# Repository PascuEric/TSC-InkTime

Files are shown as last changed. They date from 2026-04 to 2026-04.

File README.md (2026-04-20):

# InkTime — Smartwatch

InkTime is an open-source, minimalist smartwatch built around an always-readable 1.54" e-paper display and optimized for month-class battery life (≥30 days on a 250 mAh LiPo). It features BLE 5.0 notifications, embedded step counting, haptic alerts, and USB-C charging.

---

## Block Diagram

```
                          ┌──────────────────────────────────────────┐
         USB-C            │           nRF52840 (U1)                  │
        ──────►──┐        │                                          │
                 │  VBUS  │  ┌─────────────────────────────────┐     │
                 ▼        │  │         I2C Bus                 │     │
          ┌──────────┐    │  │  SDA P0.06 / SCL P0.07          │     │
          │ BQ25180  │◄───┼──┤  Pull-up 3K3 to 3V3             │     │
          │  (IC1)   │    │  │                                 │     │
          │ Charger  │    │  │  BQ25180 (0x6A)  RT6160 (0x75)  │     │
          └────┬─────┘    │  │  MAX17048 (0x36) BMA421 (0x18)  │     │
               │ SYS      │  │  DRV2605L (0x5A)                │     │
          ┌────▼─────┐    │  └─────────────────────────────────┘     │
          │ RT6160   │◄───┤                                          │
          │  (IC9)   │    │  ┌─────────────────────────────────┐     │
          │Buck-Boost│    │  │        SPI Bus                  │     │
          └────┬─────┘    │  │  SCK P0.02 / MOSI P0.03         │     │
               │ 3V3      │  │  CS P0.05 / DC P0.15            │     │
               ▼          │  │  RST P0.16 / BUSY P0.17         │     │
    ┌──────────────────┐  │  │  PFET gate P1.01                │     │
    │   3V3 Power Rail │  │  │                                 │     │
    └─┬───┬───┬───┬────┘  │  │  E-Paper 1.54" 200x200 (J1)     │     │
      │   │   │   │       │  │  via SI1308EDL MOSFET (Q3)      │     │
      │   │   │   │       │  └─────────────────────────────────┘     │
      │   │   │   │       │                                          │
      │   │   │   │       │  GPIO                                    │
      │   │   │   └───────┼──► SW_UP P0.13 / SW_DN P0.14             │
      │   │   │           │    SW_ENT P1.00                          │
      │   │   │           │  INT: BMA421 INT1→P0.08 INT2→P1.08       │
      │   │   │           │       MAX17048 ALRT→P0.10                │
      │   │   │           │       BQ25180 /INT→P0.11                 │
      │   │   │           │       HAPTIC_EN→P0.12                    │
      │   │   │           │                                          │
      │   │   │           │  RF: ANT→L1(3.9nH)→L3(15nH)→ANT1         │
      │   │   │           │  USB: D+/D-→USBLC6(D3)→USB-C (J4)        │
      │   │   │           │  SWD: SWDIO/SWDCLK/RESET→TC2030 (J2)     │
      │   │   │           └──────────────────────────────────────────┘
      │   │   │
      │   │  ┌▼────────────┐    ┌──────────────┐
      │   │  │  DRV2605L   ├───►│  ERM Motor   │
      │   │  │  (IC2) I2C  │    │  (Haptic)    │
      │   │  └─────────────┘    └──────────────┘
      │   │
      │  ┌▼────────────┐
      │  │   BMA421    │
      │  │   (IC3) I2C │  INT1→P0.08 / INT2→P1.08
      │  └─────────────┘
      │
     ┌▼────────────┐
     │  MAX17048   │
     │  (U3) I2C   │  ALRT→P0.10
     └─────────────┘

  ┌──────────┐
  │  LiPo    │──VBAT──► BQ25180 (BAT) ──► MAX17048 (BAT/VDD)
  │ 250 mAh  │
  └──────────┘
```

---

## Bill of Materials (BOM)

| Qty | Ref | Component | Package | Description | JLCPCB | Datasheet |
|-----|-----|---|---|---|---|---|
| 1 | U1 | nRF52840-QIAA-R | aQFN73 | MCU BLE 5.0 + USB 2.0 | — | [Link](https://infocenter.nordicsemi.com/pdf/nRF52840_PS_v1.7.pdf) |
| 1 | IC1 | BQ25180YBGR | DSBGA-8 | LiPo charger / power path | [C3682423](https://jlcpcb.com/partdetail/TexasInstruments-BQ25180YBGR/C3682423) | [Link](https://www.ti.com/lit/ds/symlink/bq25180.pdf) |
| 1 | IC9 | RT6160AWSC | WLCSP-15 | Buck-boost 3.3V regulator | [C7065276](https://jlcpcb.com/partdetail/Richtek-RT6160AWSC/C7065276) | [Link](https://www.richtek.com/assets/product_file/RT6160A/DS6160A-00.pdf) |
| 1 | U3 | MAX17048G+T10 | DFN-8 | Fuel gauge I2C | — | [Link](https://datasheets.maximintegrated.com/en/ds/MAX17048-MAX17049.pdf) |
| 1 | IC3 | BMA421 | LGA-12 | Accelerometer + step counter | — | [Link](https://www.bosch-sensortec.com/media/boschsensortec/downloads/datasheets/bst-bma421-ds000.pdf) |
| 1 | IC2 | DRV2605YZFR | DSBGA-9 | Haptic driver ERM/LRA | — | [Link](https://www.ti.com/lit/ds/symlink/drv2605l.pdf) |
| 1 | Q3 | SI1308EDL-T1-GE3 | SC-70 | N-ch MOSFET EPD power gate | — | [Link](https://www.vishay.com/docs/63587/si1308edl.pdf) |
| 1 | DMG2305UX-7 | DMG2305UX-7 | SOT-23 | P-ch MOSFET EPD drive | — | — |
| 1 | ANT1 | 2450AT18B100E | SMD 3216 | 2.45 GHz chip antenna | — | [Link](https://www.johansontechnology.com/datasheets/2450AT18B100E/2450AT18B100E.pdf) |
| 1 | J4 | KH-TYPE-C-16P | THT | USB-C 16-pin connector | — | — |
| 1 | D3 | USBLC6-2SC6Y | SOT-23-6 | USB ESD protection | — | [Link](https://www.st.com/resource/en/datasheet/usblc6-2.pdf) |
| 3 | D2,D4,D5 | MBR0530 | SOD-123 | Schottky diode 30V 500mA | — | — |
| 1 | J2 | TC2030-IDC | PCB footprint | Tag-Connect SWD debug | — | [Link](https://www.tag-connect.com/wp-content/uploads/bsk-pdf-manager/TC2030-IDC_1.pdf) |
| 1 | J1 | 503480-2400 | FPC 24-pin | E-paper FPC connector 0.5mm | — | [Mouser](https://www.mouser.co.uk/ProductDetail/Molex/503480-2400) |
| 3 | SW_UP,SW_DN,SW_ENT | EVP-AKE31A | SMD | Tactile button Panasonic | — | — |
| 1 | X1 | 32 MHz crystal | 2016 SMD | HFXO nRF52840 | — | — |
| 1 | X2 | 32.768 kHz crystal | 3215 SMD | LFXO RTC nRF52840 | — | — |
| 1 | L7 | FTC252012SR47MBCA | 2520 | 0.47 µH RT6160 switching | [C5832368](https://jlcpcb.com/partdetail/6763488-FTC252012SR47MBCA/C5832368) | — |
| 1 | L2 | 10 µH | 0402 | RT6160 power stage | — | — |
| 1 | L3 | 15 nH | 0402 | RF matching network | — | — |
| 1 | L1 | 3.9 nH | 0402 | RF matching network | — | — |
| 1 | L5 | 68 µH | 0402 | EPD boost converter | — | — |
| 5 | C5,C7,C8,C12,C19 | 100 nF | 0201 | Decoupling nRF52840 | — | — |
| 4 | C1,C2,C17,C18 | 12 pF | 0201 | Crystal load caps | — | — |
| 6 | C29–C32,C37,C38 | 1 µF | 0201 | Bulk decoupling | — | — |
| 3 | C23,C27,C42 | 0.1 µF | 0201 | Decoupling | — | — |
| 2 | C25,C33 | 22 µF | 0402 | RT6160 output caps | — | — |
| 3 | C14,C20,C21 | 4.7 µF | 0402 | Bulk decoupling | — | — |
| 1 | C43 | 4.7 µF | 0402 | DECUSB nRF52840 | — | — |
| 1 | C24 | 10 µF | 0402 | RT6160 input cap | — | — |
| 9 | EPD_C1..C12 | 1 µF/50V | 0402 | EPD supply caps | — | — |
| 1 | C15 | 1.0 µF | 0201 | DEC4/6 nRF52840 | — | — |
| 1 | C11 | 100 pF | 0201 | RF matching | — | — |
| 2 | C3,C4 | 1 pF | 0201 | RF matching | — | — |
| 1 | C9 | 820 pF | 0201 | RF decoupling | — | — |
| 2 | R17,R18 | 3.3 kΩ | 0201 | I2C pull-ups SDA/SCL | — | — |
| 3 | R5,R7,R8 | 10 kΩ | 0201 | Button pull-ups | — | — |
| 2 | R1_USB,R2_USB | 5.1 kΩ | 0201 | USB CC1/CC2 resistors | — | — |
| 14 | TP_* | Test pad | TP20R | Test points | — | — |
| 1 | SJ1 | Solder jumper | SMD | Config jumper | — | — |

---

## Hardware Functionality Description

### Power Architecture

```
USB 5V → BQ25180 (IN) → BQ25180 (SYS) → RT6160 (VIN) → 3.3V rail
LiPo   → BQ25180 (BAT) and LiPo → MAX17048 (BAT/VDD)
```

**BQ25180 (IC1)** handles LiPo charging and power-path management. When USB is present, it powers the system from USB and charges the battery simultaneously without brownout on connect/disconnect. TS/MR strapped to GND (R9, 10kΩ) for Rev A. Decoupling: C37 (1µF on IN), C39 (10µF on SYS), C38 (1µF on BAT).

**RT6160 (IC9)** is a buck-boost maintaining stable 3.3V across the full LiPo discharge range (4.2V → 3.0V). VSEL tied low for 3.3V output. EN tied to VSYS (always on when SYS present). Switching inductor L7 (0.47µH) placed close to SW pins. Output caps C25 + C33 (22µF each).

**MAX17048 (U3)** reports battery state-of-charge over I2C (0x36) using the ModelGauge algorithm, requiring no sense resistor. ALRT output (active-low) on P0.10 wakes MCU when battery drops below threshold.

### MCU — nRF52840 (U1)

ARM Cortex-M4F, 64 MHz, BLE 5.0, USB 2.0 Full Speed. Normal-voltage mode (VDD = 3.3V). Internal DC/DC regulator (REG1) enabled in firmware to reduce active-mode current.

Decoupling placed directly at MCU pins: DEC1 → C7 (100nF), DEC3 → C8 (100nF), DEC4/DEC6 → C15 (1µF), DECUSB → C43 (4.7µF). DC/DC network: DCC → L2 (10µH) → L3 (15nH) → DEC4/6 node.

### I2C Bus

SDA P0.06 / SCL P0.07, pull-ups R17+R18 (3.3kΩ to 3V3), 100 kHz default.

| Device | Address | Function |
|---|---|---|
| BMA421 (IC3) | 0x18 | Accelerometer + step counter |
| MAX17048 (U3) | 0x36 | Fuel gauge |
| DRV2605L (IC2) | 0x5A | Haptic driver |
| BQ25180 (IC1) | 0x6A | Charger / power path |
| RT6160 (IC9) | 0x75 | Buck-boost regulator |

### E-Paper Display (J1)

1.54" 200×200 e-paper via Molex 503480-2400 24-pin FPC connector (0.5mm pitch). SPI communication. VEPD switched by SI1308EDL N-ch MOSFET (Q3, gate P1.01) for complete power gating between updates. EPD boost circuit: D2, D4, D5 (MBR0530) + L5 (68µH) + DMG2305UX-7 generates PREVGL/PREVGH panel voltages. Optional DNP series resistors on SPI lines prevent back-powering when VEPD off.

### Accelerometer — BMA421 (IC3)

Embedded step counter running autonomously. I2C 0x18 (CSB high, SDO low). INT1 → P0.08 for motion/step wake; INT2 → P1.08 for secondary events. Placed away from ERM motor to avoid false motion coupling.

### Haptics — DRV2605L (IC2)

Drives ERM motor via I2C (0x5A). EN pin P0.12 shuts down driver completely between events. Built-in waveform library selectable by effect ID over I2C.

### RF — ANT1

Matching network: ANT → L1 (3.9nH) → L3 (15nH) → C3/C4 (1pF to GND) → 2450AT18B100E chip antenna. Antenna at PCB edge with physical cutout and GND keepout underneath.

### USB-C (J4)

USB 2.0 FS. D+/D- differential pair with matched lengths. USBLC6-2SC6Y (D3) ESD protection at connector entry. R1_USB + R2_USB (5.1kΩ each) on CC1/CC2 for USB-C sink detection.

### Energy Budget

| Condition | Current | Fraction | Avg µA |
|---|---|---|---|
| Deep sleep | ~3 µA | 98.8% | ~3.0 |
| EPD partial refresh (2s/min) | ~8 mA | 0.13% | ~10.4 |
| BLE notification | ~15 mA | 0.05% | ~7.5 |
| Haptic event | ~50 mA | 0.02% | ~10.0 |
| **Total** | | | **~31 µA** |

250 mAh / 0.031 mA ≈ **~33 days** typical use.

---

## nRF52840 Pin Assignment

| Pin | Net | Dir | Connected to | Rationale |
|-----|-----|-----|---|---|
| P0.02 | SCK | OUT | EPD display | SPI — high-speed Port 0 peripheral |
| P0.03 | MOSI | OUT | EPD display | SPI data out |
| P0.05 | EPD_CS | OUT | EPD display | SPI chip select |
| P0.06 | SDA | I/O | All I2C ICs | Nordic reference I2C pin |
| P0.07 | SCL | OUT | All I2C ICs | Nordic reference I2C pin |
| P0.08 | IMU_INT1 | IN | BMA421 INT1 | GPIO sense, wake from deep sleep |
| P0.10 | ALERT | IN | MAX17048 ALRT | Low battery wake |
| P0.11 | PMIC_INT | IN | BQ25180 /INT | Charger event interrupt |
| P0.12 | HAPTIC_EN | OUT | DRV2605L EN | Haptic driver shutdown between events |
| P0.13 | SW_UP | IN | Button UP | GPIO sense + internal pull-up, wake capable |
| P0.14 | SW_DN | IN | Button DOWN | GPIO sense + internal pull-up, wake capable |
| P0.15 | EPD_DC | OUT | EPD display | Data/command select |
| P0.16 | EPD_RST | OUT | EPD display | Panel reset |
| P0.17 | EPD_BUSY | IN | EPD display | Busy status |
| P0.18/RESET | nRESET | IN | TC2030 pin 6 | Dedicated hardware reset |
| P0.00/XL1 | LFXO | — | X2 crystal | 32.768 kHz RTC |
| P0.01/XL2 | LFXO | — | X2 crystal | 32.768 kHz RTC |
| XC1/XC2 | HFXO | — | X1 crystal | 32 MHz RF/CPU |
| ANT | RF | — | L1→L3→ANT1 | Antenna matching network |
| VBUS | Detect | IN | USB-C VBUS | USB attach detection |
| D+/D- | USB | I/O | USBLC6→J4 | USB 2.0 FS differential pair |
| SWDIO | SWD | I/O | TC2030 pin 2 | Programming + debug |
| SWDCLK | SWD | IN | TC2030 pin 4 | Programming + debug |
| P1.00 | SW_ENT | IN | Button ENTER | GPIO sense + pull-up, wake capable |
| P1.01 | EPD_PWR | OUT | Q3 gate | EPD power gate control |
| P1.08 | IMU_INT2 | IN | BMA421 INT2 | Secondary accel events |
| DCC | DC/DC | — | L2 (10µH) | Internal regulator inductor |
| DEC1 | Decoupling | — | C7 (100nF) | Core decoupling |
| DEC3 | Decoupling | — | C8 (100nF) | Core decoupling |
| DEC4/DEC6 | Decoupling | — | C15 (1µF) | DC/DC output node |
| DECUSB | Decoupling | — | C43 (4.7µF) | USB PHY decoupling |

---

## PCB Design Notes

**Stackup:** 2-layer, FR4, 1.6mm. Top + Bottom copper (1oz), green soldermask, white silkscreen.

**Placement:** nRF52840 centered; RF matching + ANT1 at top-right board edge with physical PCB cutout and GND keepout under antenna; BQ25180 + RT6160 grouped away from antenna; BMA421 separated from ERM motor; all 100nF decoupling within 0.5mm of VDD pins; TC2030 at board edge.

**Trace widths:** Power (3V3, VBAT) = 0.3mm; signals (SPI, I2C, GPIO) ≥ 0.15mm; USB D+/D- = 0.15mm matched length. No 90° angles.

**GND:** Polygon on Top + Bottom layers, via stitching throughout, especially dense around RF section.

---

## Repository Structure

```
├── Hardware/
│   ├── schemTSC.sch
│   └── schemaPCB.brd
├── Manufacturing/
│   ├── gerbers.zip
│   ├── bom.csv
│   └── pick-n-place.csv
├── Mechanical/
│   ├── casedPCB.step
│   └── exploded_case.step
├── Images/
│   ├── exploded_render.png
│   ├── PCB_render.png
│   ├── PCB_top.png
│   └── PCB_bottom.png
├── LICENSE
└── README.md
```

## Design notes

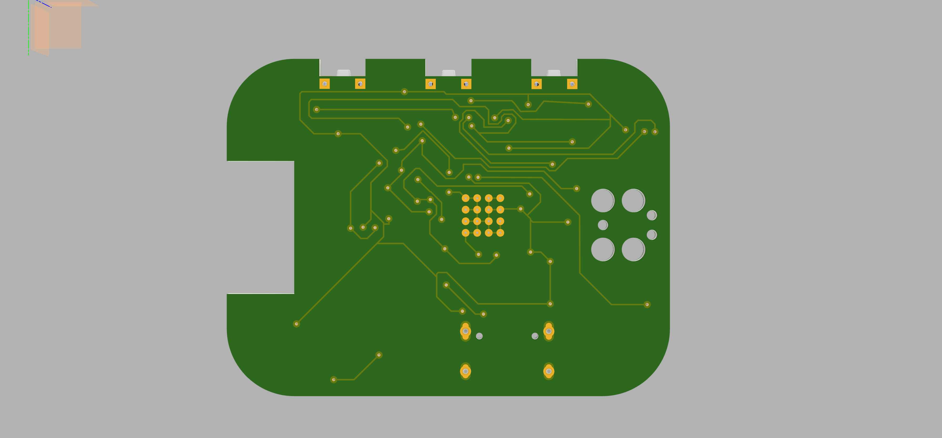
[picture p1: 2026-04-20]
images/PCB_bottom.png

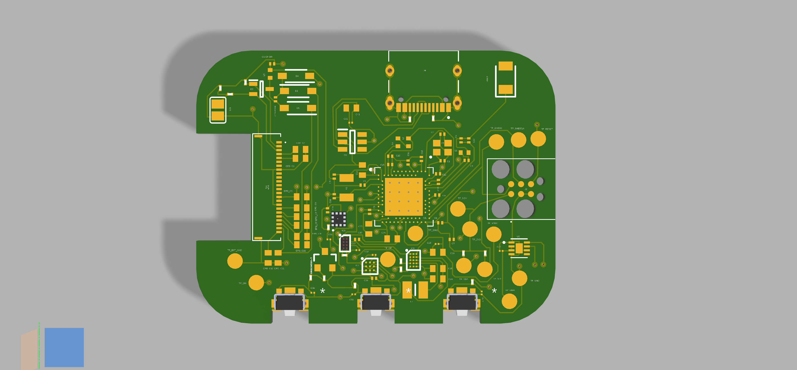
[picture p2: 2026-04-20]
images/PCB_top.png

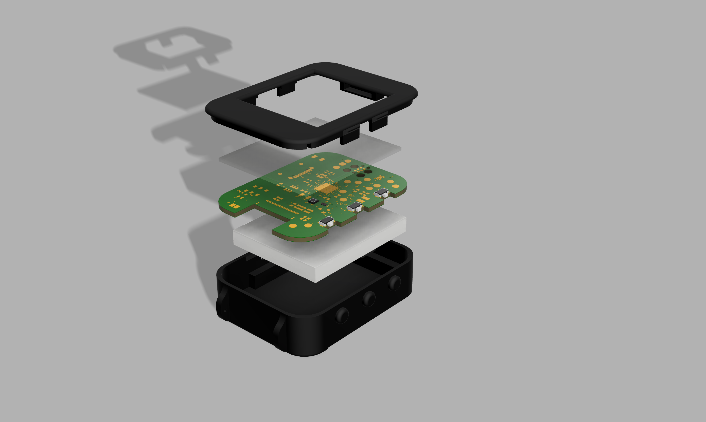
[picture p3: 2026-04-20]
images/exploded_render.png

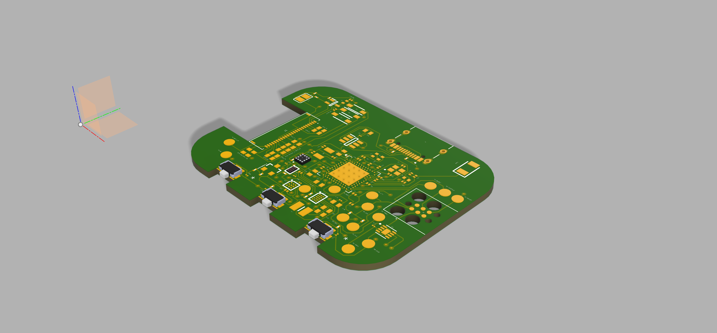
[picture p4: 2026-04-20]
images/PCB_render.png

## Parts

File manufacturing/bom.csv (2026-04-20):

Qty | Value | Device | Package | Parts | Description | ARROW_PART_NUMBER | ARROW_PRICE-STOCK | AVAILABILITY | CHECK_PRICES | COPYRIGHT | DESCRIPTION | DIGI-KEY_PART_NUMBER_1 | DIGI-KEY_PART_NUMBER_2 | DIGI-KEY_PART_NUMBER_3 | HEIGHT | JLCPCB | MANUFACTURER_NAME | MANUFACTURER_PART_NUMBER | MF | MOUSER_PART_NUMBER | MOUSER_PRICE-STOCK | MP | PACKAGE | POPULARITY | PRICE | PROD_ID | PURCHASE-URL | SNAPEDA_LINK | SPICEMODEL | SPICEPREFIX | TP_SIGNAL_NAME | VALUE
1 |  | ESP32_C6_LIBRARY_7_JUMPER_SJ | ESP32_C6_LIBRARY_7_JUMPER_SJ | SJ1 | SMD solder JUMPER |  |  |  |  |  |  |  |  |  |  |  |  |  |  |  |  |  |  | 3
2 | 0 | CPF0201D7K68C1_CPF0201D7K68C1 | CPF0201D7K68C1_0201 | R2, R4 | 7.68k 0201 Thin Film Surface Mount Fixed Resistor +/-0.5% 0.031W CPF0201D7K68C1
1 | 0 | ERA-1AEB3401C_CPF0201D7K68C1 | ERA-1AEB3401C_0201 | R3 | 7.68k 0201 Thin Film Surface Mount Fixed Resistor +/-0.5% 0.031W CPF0201D7K68C1
3 | 0.1uF | GRM011R60J152KE01L_2_GRM011R60J152KE01L | GRM011R60J152KE01L_2_CAPC0201X13N | C23, C27, C42 | Check availability |  |  | In Stock | https://www.snapeda.com/parts/GRM011R60J152KE01L/Murata/view-part/?ref=eda |  | SMD Capacitor X5R(EIA) with Capacitance: 1500pF Tol. 10%. Rated Voltage: 6.3Vdc |  |  |  |  |  |  |  | Murata |  |  | GRM011R60J152KE01L | 0201 Murata |  | None |  |  | https://www.snapeda.com/parts/GRM011R60J152KE01L/Murata/view-part/?ref=snap
1 | 0.1uF | NORDIC_NRF_3_CAPACITOR_0201_L | NORDIC_NRF_3_RESC0201_L | C34 | Generic chip capacitor
1 | 0.1uF/50V | ESP32_C6_LIBRARY_1_ESP32_WROVER_EAGLE-LTSPICE_CC0402 | ESP32_C6_LIBRARY_1_ESP32_WROVER_EAGLE-LTSPICE_C0402 | EPD_C5 | CAPACITOR, European symbol |  |  |  |  |  |  |  |  |  |  |  |  |  |  |  |  |  |  |  |  |  |  |  | NONE | C
1 | 0.47 | ERA-1AEB3401C_CPF0201D7K68C1 | ERA-1AEB3401C_0201 | R1_EP_DR | 7.68k 0201 Thin Film Surface Mount Fixed Resistor +/-0.5% 0.031W CPF0201D7K68C1
1 | 1.0µF | NORDIC_NRF_3_CAPACITOR_0201_L | NORDIC_NRF_3_RESC0201_L | C15 | Generic chip capacitor
5 | 100nF | NORDIC_NRF_3_CAPACITOR_0201_L | NORDIC_NRF_3_RESC0201_L | C5, C7, C8, C12, C19 | Generic chip capacitor
1 | 100pF | NORDIC_NRF_3_CAPACITOR_0201_L | NORDIC_NRF_3_RESC0201_L | C11 | Generic chip capacitor
1 | 10K | CPF0201D7K68C1_CPF0201D7K68C1 | CPF0201D7K68C1_0201 | R_PWR_EPD | 7.68k 0201 Thin Film Surface Mount Fixed Resistor +/-0.5% 0.031W CPF0201D7K68C1
2 | 10K | ERA-1AEB3401C_CPF0201D7K68C1 | ERA-1AEB3401C_0201 | R2_EP_DR, R9 | 7.68k 0201 Thin Film Surface Mount Fixed Resistor +/-0.5% 0.031W CPF0201D7K68C1
3 | 10k | CPF0201D7K68C1_CPF0201D7K68C1 | CPF0201D7K68C1_0201 | R5, R7, R8 | 7.68k 0201 Thin Film Surface Mount Fixed Resistor +/-0.5% 0.031W CPF0201D7K68C1
1 | 10uF | ESP32_C6_LIBRARY_1_ESP32_WROVER_EAGLE-LTSPICE_CC0402 | ESP32_C6_LIBRARY_1_ESP32_WROVER_EAGLE-LTSPICE_C0402 | C24 | CAPACITOR, European symbol |  |  |  |  |  |  |  |  |  |  |  |  |  |  |  |  |  |  |  |  |  |  |  | NONE | C
2 | 10uF | NORDIC_NRF_3_CAPACITOR_0201_L | NORDIC_NRF_3_RESC0201_L | C1-EP-DR, C39 | Generic chip capacitor
1 | 10µH | NORDIC_NRF_2_INDUCTOR_0402_L | NORDIC_NRF_2_RESC0402_L | L2 | Generic chip inductor
4 | 12pF | NORDIC_NRF_3_CAPACITOR_0201_L | NORDIC_NRF_3_RESC0201_L | C1, C2, C17, C18 | Generic chip capacitor
1 | 15nH | NORDIC_NRF_2_INDUCTOR_0402_L | NORDIC_NRF_2_RESC0402_L | L3 | Generic chip inductor
2 | 1pF | NORDIC_NRF_3_CAPACITOR_0201_L | NORDIC_NRF_3_RESC0201_L | C3, C4 | Generic chip capacitor
6 | 1uF | GRM011R60J152KE01L_2_GRM011R60J152KE01L | GRM011R60J152KE01L_2_CAPC0201X13N | C29, C30, C31, C32, C37, C38 | Check availability |  |  | In Stock | https://www.snapeda.com/parts/GRM011R60J152KE01L/Murata/view-part/?ref=eda |  | SMD Capacitor X5R(EIA) with Capacitance: 1500pF Tol. 10%. Rated Voltage: 6.3Vdc |  |  |  |  |  |  |  | Murata |  |  | GRM011R60J152KE01L | 0201 Murata |  | None |  |  | https://www.snapeda.com/parts/GRM011R60J152KE01L/Murata/view-part/?ref=snap
9 | 1uF/50V | ESP32_C6_LIBRARY_1_ESP32_WROVER_EAGLE-LTSPICE_CC0402 | ESP32_C6_LIBRARY_1_ESP32_WROVER_EAGLE-LTSPICE_C0402 | EPD_C1, EPD_C2, EPD_C6, EPD_C7, EPD_C8, EPD_C9, EPD_C10, EPD_C11, EPD_C12 | CAPACITOR, European symbol |  |  |  |  |  |  |  |  |  |  |  |  |  |  |  |  |  |  |  |  |  |  |  | NONE | C
1 | 2.2 | ERA-1AEB3401C_CPF0201D7K68C1 | ERA-1AEB3401C_0201 | R_TYPE_SEL | 7.68k 0201 Thin Film Surface Mount Fixed Resistor +/-0.5% 0.031W CPF0201D7K68C1
3 | 2025-10-22_07-23-44_LIBRARY_EVP-AKE31ASW_EVP-AKE31A_PAN | 2025-10-22_07-23-44_LIBRARY_EVP-AKE31ASW_EVP-AKE31A_PAN | 2025-10-22_07-23-44_LIBRARY_SW_EVP-AKE31A_PAN | SW_DN, SW_ENT, SW_UP |  |  |  |  |  | Copyright (C) 2025 Ultra Librarian. All rights reserved. |  | P123437TR-ND | P123437CT-ND | P123437DKR-ND |  |  | Panasonic | EVP-AKE31A
1 | 20V/4.2A/52mΩ/1.4W | ESP32_C6_LIBRARY_4_ESP32_WROVER_SPARKFUN-DISCRETESEMI_MOSFET_PCH-DMG2305UX-7 | ESP32_C6_LIBRARY_4_ESP32_C6_LIBRARY_4_ESP32_C6_LIBRARY_4_ESP32_C6_LIBRARY_4_ESP32_WROVER_SPARKFUN-DISCRETESEMI_SOT23-3 | DMG2305UX-7 | P-channel MOSFETs |  |  |  |  |  |  |  |  |  |  |  |  |  |  |  |  |  |  |  |  | TRAN-14388 |  |  |  |  |  | 20V/4.2A/52mΩ/1.4W
2 | 22uF | ESP32_C6_LIBRARY_1_ESP32_WROVER_EAGLE-LTSPICE_CC0402 | ESP32_C6_LIBRARY_1_ESP32_WROVER_EAGLE-LTSPICE_C0402 | C25, C33 | CAPACITOR, European symbol |  |  |  |  |  |  |  |  |  |  |  |  |  |  |  |  |  |  |  |  |  |  |  | NONE | C
1 | 2450AT18B100E | 2450AT18B100E_2450AT18B100E | 2450AT18B100E_ANTC3216X140N | ANT1 | Antennas 2.45GHz ANTENNA | 2450AT18B100E | https://www.arrow.com/en/products/2450at18b100e/johanson-dielectrics?utm_currency=USD&region=nac |  |  |  | Antennas 2.45GHz ANTENNA |  |  |  | 1.4mm |  | JOHANSON TECHNOLOGY | 2450AT18B100E |  | 609-2450AT18B100E | https://www.mouser.co.uk/ProductDetail/Johanson-Technology/2450AT18B100E?qs=yCnrNFeXz%252Bh5MFsFIXGZGA%3D%3D
1 | 3.9nH | NORDIC_NRF_2_INDUCTOR_0402_L | NORDIC_NRF_2_RESC0402_L | L1 | Generic chip inductor
1 | 32.768kHz | NORDIC_NRF_1_XTAL_32KHZ | NORDIC_NRF_1_XTAL_3215_N | X2
1 | 32MHz | NORDIC_NRF_XTAL_32MHZ | NORDIC_NRF_BT-XTAL_2016_N | X1
2 | 3K3 | CPF0201D7K68C1_CPF0201D7K68C1 | CPF0201D7K68C1_0201 | R17, R18 | 7.68k 0201 Thin Film Surface Mount Fixed Resistor +/-0.5% 0.031W CPF0201D7K68C1
1 | 4.7uF | ESP32_C6_LIBRARY_1_ESP32_WROVER_EAGLE-LTSPICE_CC0402 | ESP32_C6_LIBRARY_1_ESP32_WROVER_EAGLE-LTSPICE_C0402 | C43 | CAPACITOR, European symbol |  |  |  |  |  |  |  |  |  |  |  |  |  |  |  |  |  |  |  |  |  |  |  | NONE | C
1 | 4.7uF/25V | NORDIC_NRF_3_CAPACITOR_0201_L | NORDIC_NRF_3_RESC0201_L | C2-EP-DR | Generic chip capacitor
3 | 4.7µF | ESP32_C6_LIBRARY_1_ESP32_WROVER_EAGLE-LTSPICE_CC0402 | ESP32_C6_LIBRARY_1_ESP32_WROVER_EAGLE-LTSPICE_C0402 | C14, C20, C21 | CAPACITOR, European symbol |  |  |  |  |  |  |  |  |  |  |  |  |  |  |  |  |  |  |  |  |  |  |  | NONE | C
1 | 4.7µF | NORDIC_NRF_3_CAPACITOR_0201_L | NORDIC_NRF_3_RESC0201_L | C6 | Generic chip capacitor
1 | 47nF | NORDIC_NRF_3_CAPACITOR_0201_L | NORDIC_NRF_3_RESC0201_L | C16 | Generic chip capacitor
1 | 503480-2400 | 503480-2400_503480-2400 | 503480-2400_5034802400 | J1 | FFC & FPC Connectors 0.5mm FPC RA SMT Dual Contact 24Ckt |  |  |  |  |  | FFC & FPC Connectors 0.5mm FPC RA SMT Dual Contact 24Ckt |  |  |  | 1.87mm |  | Molex | 503480-2400 |  | 538-503480-2400 | https://www.mouser.co.uk/ProductDetail/Molex/503480-2400?qs=OAhjpuo3Vu7efIoxFh9AOw%3D%3D
1 | 5K1 | CPF0201D7K68C1_CPF0201D7K68C1 | CPF0201D7K68C1_0201 | R1_USB | 7.68k 0201 Thin Film Surface Mount Fixed Resistor +/-0.5% 0.031W CPF0201D7K68C1
1 | 5K1 | ERA-1AEB3401C_CPF0201D7K68C1 | ERA-1AEB3401C_0201 | R2_USB | 7.68k 0201 Thin Film Surface Mount Fixed Resistor +/-0.5% 0.031W CPF0201D7K68C1
1 | 68uH | NORDIC_NRF_2_INDUCTOR_0402_L | NORDIC_NRF_2_RESC0402_L | L5 | Generic chip inductor
1 | 820pF | NORDIC_NRF_3_CAPACITOR_0201_L | NORDIC_NRF_3_RESC0201_L | C9 | Generic chip capacitor
1 | BMA421 | BMA423_BMA423 | BMA423_BMA423 | IC3 | Accelerometers Triaxial low-g 12bit Acceleration Sensor | BMA423 | https://www.arrow.com/en/products/bma423/bosch |  |  |  | Accelerometers Triaxial low-g 12bit Acceleration Sensor |  |  |  | 1mm |  | BOSCH | BMA423 |  | 262-BMA423 | https://www.mouser.co.uk/ProductDetail/Bosch-Sensortec/BMA423?qs=HXFqYaX1Q2xC%252BSgeGoX3mg%3D%3D
1 | BQ25180YBGR | BQ25180YBGR_BQ25180YBGR | BQ25180YBGR_BGA8C40P2X4_100X155X50 | IC1 | Charger IC Lithium Ion/Polymer, Lithium Iron Phosphate 8-DSBGA (1.6x1.1) | BQ25180YBGR | https://www.arrow.com/en/products/bq25180ybgr/texas-instruments?utm_currency=USD&region=nac |  |  |  | Charger IC Lithium Ion/Polymer | Lithium Iron Phosphate 8-DSBGA (1.6x1.1) |  |  |  | 0.5mm |  | Texas Instruments | BQ25180YBGR |  | 595-BQ25180YBGR | https://www.mouser.co.uk/ProductDetail/Texas-Instruments/BQ25180YBGR?qs=doiCPypUmgEWjAK%252BJAX6Tw%3D%3D
1 | DRV2605YZFR | DRV2605YZFR_DRV2605YZFR | DRV2605YZFR_BGA9C50P3X3_144X144X62 | IC2 | Haptic Driver for ERM/LRA with Built-In Library and Smart Loop Architecture | DRV2605YZFR | https://www.arrow.com/en/products/drv2605yzfr/texas-instruments?region=nac |  |  |  | Haptic Driver for ERM/LRA with Built-In Library and Smart Loop Architecture |  |  |  | 0.625mm |  | Texas Instruments | DRV2605YZFR
3 | ESP32_C6_LIBRARY_5_MBR0530 | ESP32_C6_LIBRARY_5_MBR0530 | ESP32_C6_LIBRARY_5_SOD3716X135N | D2, D4, D5 | ON SEMICONDUCTOR - MBR0530 - DIODE, SCHOTTKY, 0.5A, 30V, SOD-123 |  |  | In Stock | https://www.snapeda.com/parts/MBR0530/Onsemi/view-part/?ref=eda |  | Diode Schottky 30 V 500mA Surface Mount SOD-123 |  |  |  |  |  |  |  | ON Semiconductor |  |  | MBR0530 | SOD-123-2 ON Semiconductor |  | None |  | https://www.snapeda.com/api/url_track_click_mouser/?unipart_id=179458&manufacturer=ON Semiconductor&part_name=MBR0530&search_term=None | https://www.snapeda.com/parts/MBR0530/Onsemi/view-part/?ref=snap
1 | FTC252012SR47MBCA | MLP2016SR47MT0S1_FTC252012SR47MBCA | MLP2016SR47MT0S1_INDC2016X100N | L7 | SMD / SMT Inductors (Coils), L=0.47?H, L x W x T : |  |  |  |  |  | SMD / SMT Inductors (Coils) | L=0.47?H | L x W x T : |  |  |  | 1mm | https://jlcpcb.com/partdetail/6763488-FTC252012SR47MBCA/C5832368 | TDK | FTC252012SR47MBCA
14 | HECTOR_WATCH_1_TPTP20R | HECTOR_WATCH_1_TPTP20R | HECTOR_WATCH_1_TP20R | TP_3.3V, TP_3V3, TP_BAT_GND, TP_GND, TP_ON, TP_OP, TP_RESET, TP_SCL, TP_SDA, TP_SWDCLK, TP_SWDIO, TP_SWO, TP_VBAT, TP_VREG | Test pad |  |  |  |  |  |  |  |  |  |  |  |  |  |  |  |  |  |  | 2
1 | KH-TYPE-C-16P | KH-TYPE-C-16P_KH-TYPE-C-16P | KH-TYPE-C-16P_KINGHELM_KH-TYPE-C-16P | J4 | Check availability |  |  | Not in stock | https://www.snapeda.com/parts/KH-TYPE-C-16P/Kinghelm/view-part/?ref=eda |  |  |  |  |  |  |  |  |  | kinghelm |  |  | KH-TYPE-C-16P | None |  | None |  |  | https://www.snapeda.com/parts/KH-TYPE-C-16P/Kinghelm/view-part/?ref=snap
1 | MAX17048G+T10 | ESP32_C6_LIBRARY_MAX17048G+T10 | ESP32_C6_LIBRARY_SON50P200X200X80-9N | U3 | Check availability |  |  | In Stock | https://www.snapeda.com/parts/MAX17048G+T10/Analog+Devices/view-part/?ref=eda |  | 3µA 1-Cell/2-Cell Fuel Gauge with ModelGauge |  |  |  |  |  |  |  | Analog Devices |  |  | MAX17048G+T10 | TDFN-8 Maxim |  | None |  | https://www.snapeda.com/api/url_track_click_mouser/?unipart_id=329239&manufacturer=Analog Devices&part_name=MAX17048G+T10&search_term=None | https://www.snapeda.com/parts/MAX17048G+T10/Analog+Devices/view-part/?ref=snap
3 | N.C. | NORDIC_NRF_3_CAPACITOR_0201_L | NORDIC_NRF_3_RESC0201_L | C10, C13, C22 | Generic chip capacitor
1 | NRF52840_QF | NORDIC_NRF_4_NRF52840_QF | NORDIC_NRF_4_AQFN50P700X700X85_HS-74N | U1 | nRF52840
1 | RT6160AWSC | RT6160AWSC_RT6160AWSC | RT6160AWSC_BGA15C40P3X5_140X230X60 | IC9 | Buck-Boost Regulator Positive Output Step-Up/Step-Down I2C DC-DC Controller IC 15-WL-CSP (BSC) (1.4x2.3) |  |  |  |  |  | Buck-Boost Regulator Positive Output Step-Up/Step-Down I2C DC-DC Controller IC 15-WL-CSP (BSC) (1.4x2.3) |  |  |  | 0.6mm |  | RICHTEK | RT6160AWSC |  | 835-RT6160AWSC | https://www.mouser.co.uk/ProductDetail/Richtek/RT6160AWSC?qs=amGC7iS6iy%2FLd9PSoixZXQ%3D%3D
1 | SI1308EDL-T1-GE3 | ESP32_C6_LIBRARY_6_SI1308EDL-T1-GE3 | ESP32_C6_LIBRARY_6_SOT65P210X110-3N | Q3 | MOSFET N-Ch 30V 1.5A TrenchFET SC70 Vishay Si1308EDL-T1-GE3 N-channel MOSFET Transistor, 1.5 A, 30 V, 3-Pin SC-70 |  |  | In Stock | https://www.snapeda.com/parts/SI1308EDL-T1-GE3/Vishay+Siliconix/view-part/?ref=eda |  | Si1308EDL-T1-GE3 N-channel MOSFET Transistor | 1.5 A | 30 V | 3-Pin SC-70 | Siliconix / Vishay SI1308EDL-T1-GE3 |  |  |  |  |  |  |  | Vishay Siliconix |  |  | SI1308EDL-T1-GE3 | SOT-323 Vishay Semiconductor |  | None |  | https://www.snapeda.com/api/url_track_click_mouser/?unipart_id=274603&manufacturer=Vishay Siliconix&part_name=SI1308EDL-T1-GE3&search_term=None | https://www.snapeda.com/parts/SI1308EDL-T1-GE3/Vishay+Siliconix/view-part/?ref=snap
1 | TC2030-IDC | TC2030-IDC_TC2030-IDC | TC2030-IDC_TC2030IDC | J2 | CABLE ADAPTER 6 POS |  |  |  |  |  | CABLE ADAPTER 6 POS |  |  |  | 19mm |  | Tag Connect | TC2030-IDC
1 | USBLC6-2SC6Y | ESP32_C6_LIBRARY_3_USBLC6-2SC6Y | ESP32_C6_LIBRARY_3_SOT95P280X145-6N | D3 | Low Cap. ESD Protection Auto SOT-23-6 STMicroelectronics USBLC6-2SC6Y, Dual Uni-Directional TVS Diode Array, 6-Pin SOT-23 |  |  | In Stock | https://www.snapeda.com/parts/USBLC6-2SC6Y/STMicroelectronics/view-part/?ref=eda |  | 17V Clamp 5A (8/20µs) Ipp Tvs Diode Surface Mount SOT-23-6 |  |  |  |  |  |  |  | STMicroelectronics |  |  | USBLC6-2SC6Y | SOT-23-6 STMicroelectronics |  | None |  |  | https://www.snapeda.com/parts/USBLC6-2SC6Y/STMicroelectronics/view-part/?ref=snap

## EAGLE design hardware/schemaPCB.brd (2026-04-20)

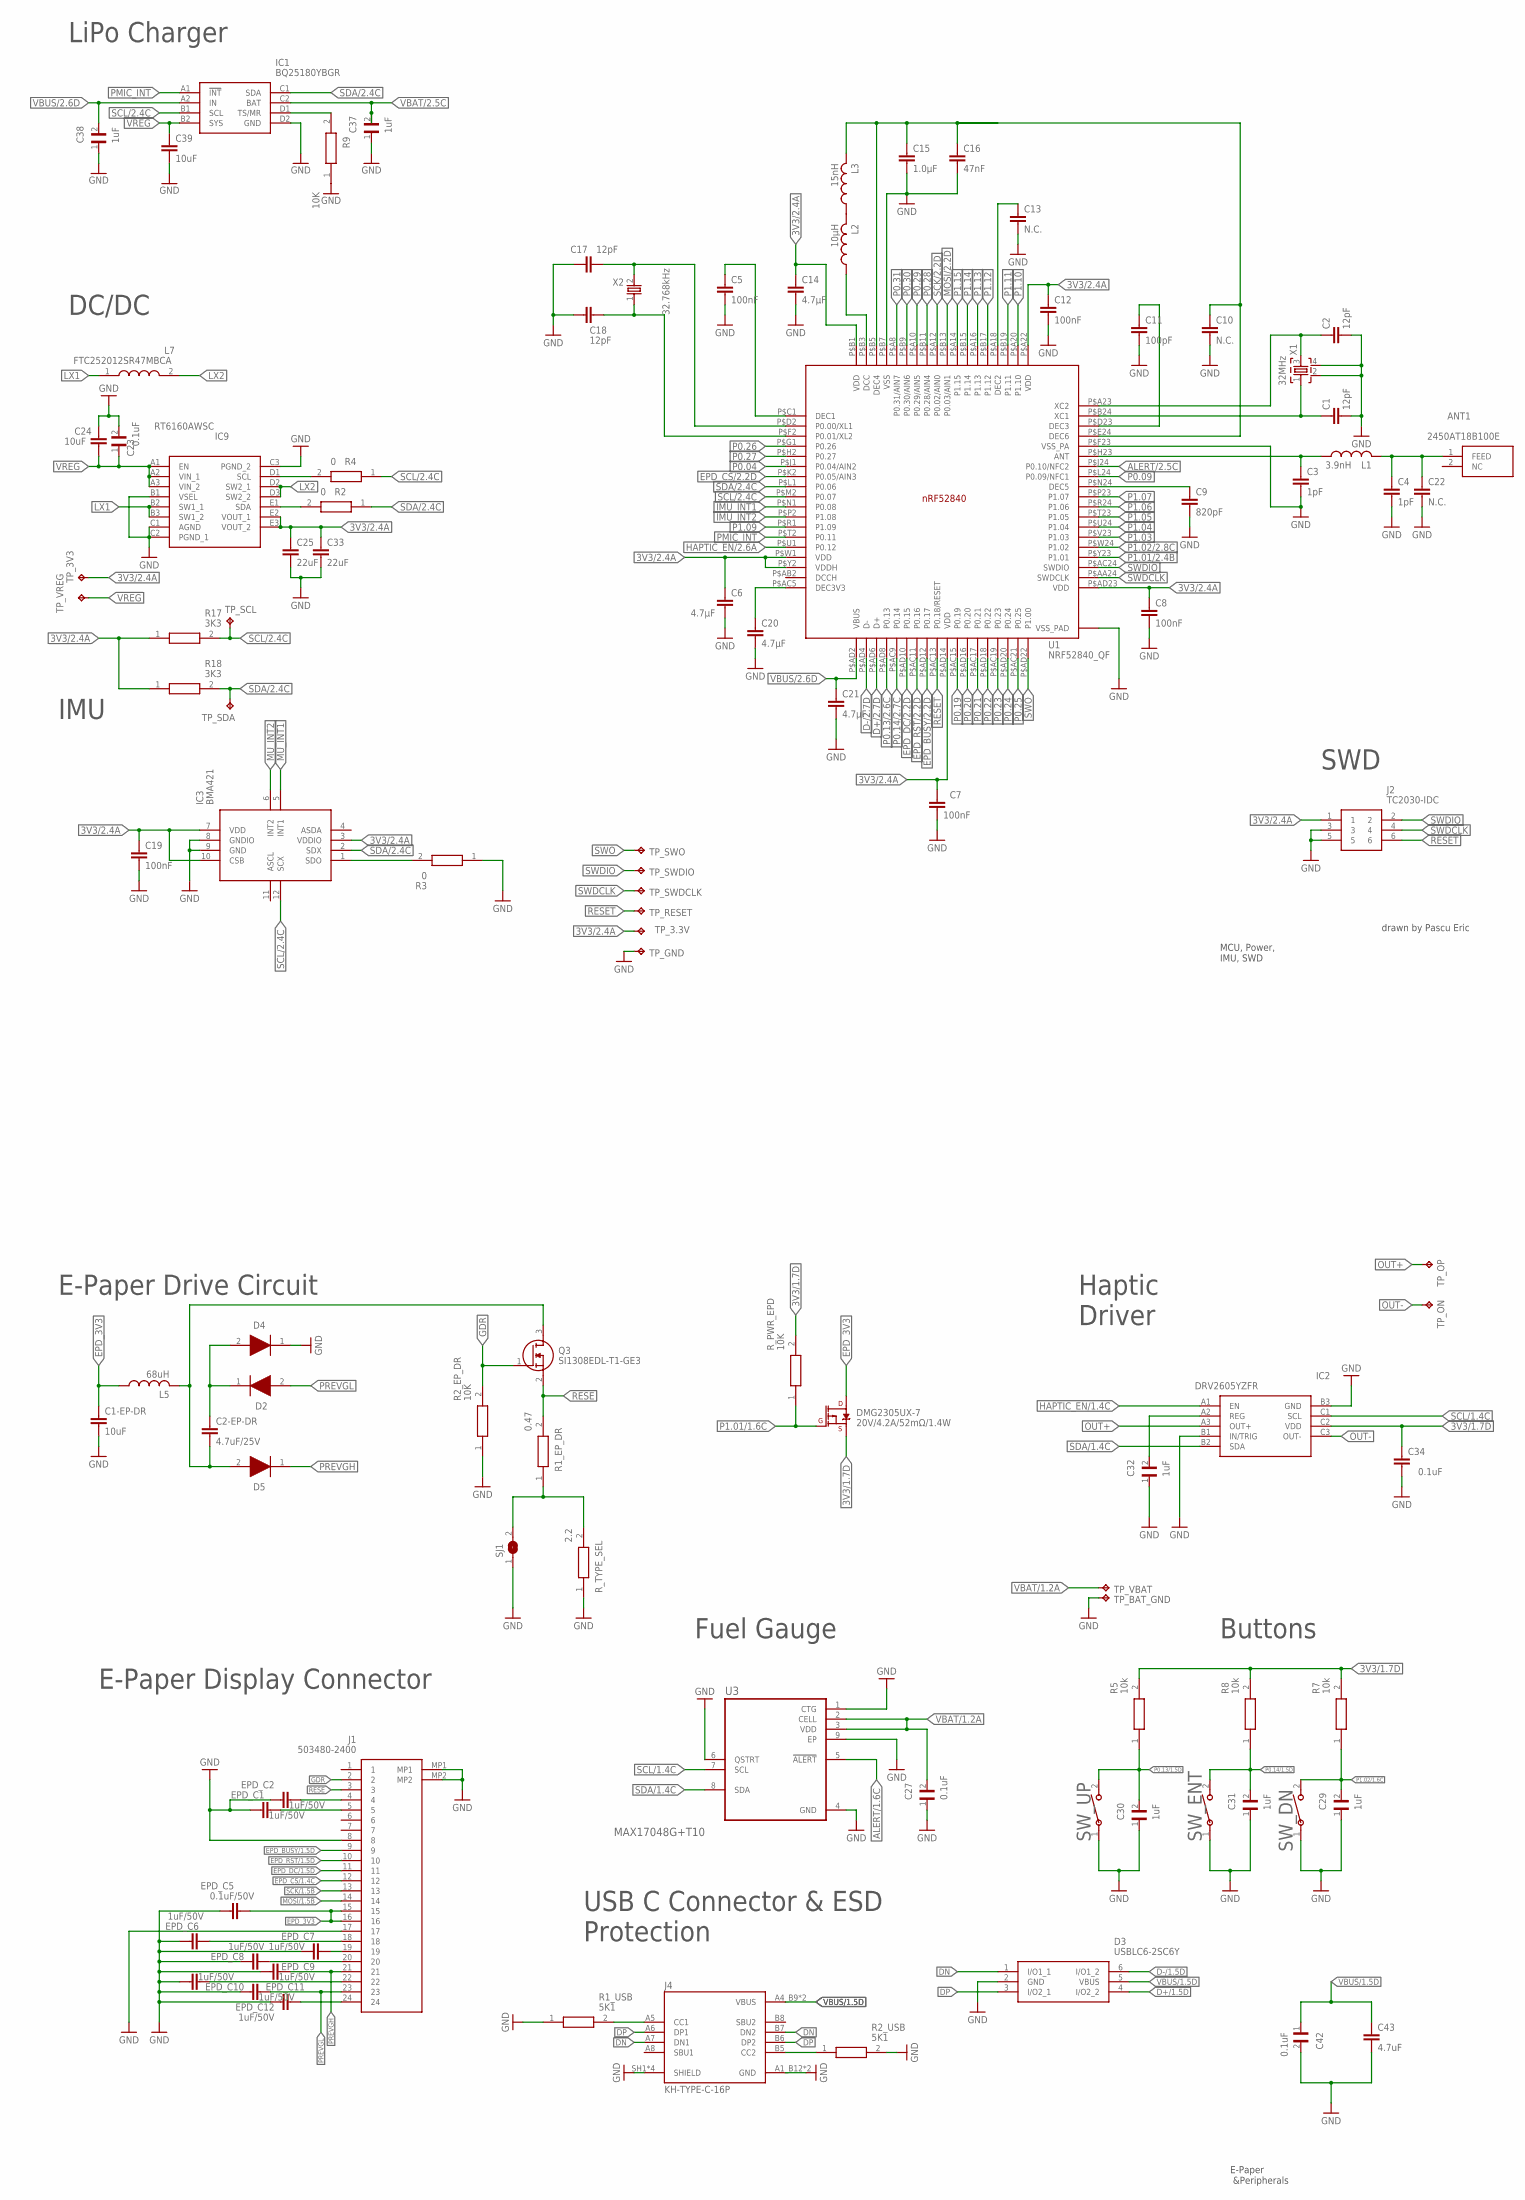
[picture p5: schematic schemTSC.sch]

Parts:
ANT1: 2450AT18B100E; 2450AT18B100E_ANTC3216X140N
C1, C2, C17, C18: 12pF; NORDIC_NRF_3_RESC0201_L
C1-EP-DR, C39: 10uF; NORDIC_NRF_3_RESC0201_L
C2-EP-DR: 4.7uF/25V; NORDIC_NRF_3_RESC0201_L
C3, C4: 1pF; NORDIC_NRF_3_RESC0201_L
C5, C7, C8, C12, C19: 100nF; NORDIC_NRF_3_RESC0201_L
C6: 4.7µF; NORDIC_NRF_3_RESC0201_L
C9: 820pF; NORDIC_NRF_3_RESC0201_L
C10, C13, C22: N.C.; NORDIC_NRF_3_RESC0201_L
C11: 100pF; NORDIC_NRF_3_RESC0201_L
C14, C20, C21: 4.7µF; ESP32_C6_LIBRARY_1_ESP32_WROVER_EAGLE-LTSPICE_C0402
C15: 1.0µF; NORDIC_NRF_3_RESC0201_L
C16: 47nF; NORDIC_NRF_3_RESC0201_L
C23, C27, C42: 0.1uF; GRM011R60J152KE01L_2_CAPC0201X13N
C24: 10uF; ESP32_C6_LIBRARY_1_ESP32_WROVER_EAGLE-LTSPICE_C0402
C25, C33: 22uF; ESP32_C6_LIBRARY_1_ESP32_WROVER_EAGLE-LTSPICE_C0402
C29, C30, C31, C32, C37, C38: 1uF; GRM011R60J152KE01L_2_CAPC0201X13N
C34: 0.1uF; NORDIC_NRF_3_RESC0201_L
C43: 4.7uF; ESP32_C6_LIBRARY_1_ESP32_WROVER_EAGLE-LTSPICE_C0402
D2, D4, D5: ESP32_C6_LIBRARY_5_MBR0530; ESP32_C6_LIBRARY_5_SOD3716X135N
D3: USBLC6-2SC6Y; ESP32_C6_LIBRARY_3_SOT95P280X145-6N
DMG2305UX-7: 20V/4.2A/52mΩ/1.4W; ESP32_C6_LIBRARY_4_ESP32_C6_LIBRARY_4_ESP32_C6_LIBRARY_4_ES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
EPD_C1, EPD_C2, EPD_C6, EPD_C7, EPD_C8, EPD_C9, EPD_C10, EPD_C11, EPD_C12: 1uF/50V; ESP32_C6_LIBRARY_1_ESP32_WROVER_EAGLE-LTSPICE_C0402
EPD_C5: 0.1uF/50V; ESP32_C6_LIBRARY_1_ESP32_WROVER_EAGLE-LTSPICE_C0402
IC1: BQ25180YBGR; BQ25180YBGR_BGA8C40P2X4_100X155X50
IC2: DRV2605YZFR; DRV2605YZFR_BGA9C50P3X3_144X144X62
IC3: BMA421; BMA423_BMA423
IC9: RT6160AWSC; RT6160AWSC_BGA15C40P3X5_140X230X60
J1: 503480-2400; 503480-2400_5034802400
J2: TC2030-IDC; TC2030-IDC_TC2030IDC
J4: KH-TYPE-C-16P; KH-TYPE-C-16P_KINGHELM_KH-TYPE-C-16P
L1: 3.9nH; NORDIC_NRF_2_RESC0402_L
L2: 10µH; NORDIC_NRF_2_RESC0402_L
L3: 15nH; NORDIC_NRF_2_RESC0402_L
L5: 68uH; NORDIC_NRF_2_RESC0402_L
L7: FTC252012SR47MBCA; MLP2016SR47MT0S1_INDC2016X100N
Q3: SI1308EDL-T1-GE3; ESP32_C6_LIBRARY_6_SOT65P210X110-3N
R1_EP_DR: 0.47; ERA-1AEB3401C_0201
R1_USB: 5K1; CPF0201D7K68C1_0201
R2, R4: 0; CPF0201D7K68C1_0201
R2_EP_DR, R9: 10K; ERA-1AEB3401C_0201
R2_USB: 5K1; ERA-1AEB3401C_0201
R3: 0; ERA-1AEB3401C_0201
R5, R7, R8: 10k; CPF0201D7K68C1_0201
R17, R18: 3K3; CPF0201D7K68C1_0201
R_PWR_EPD: 10K; CPF0201D7K68C1_0201
R_TYPE_SEL: 2.2; ERA-1AEB3401C_0201
SJ1: ESP32_C6_LIBRARY_7_JUMPER_SJ
SW_DN: 2025-10-22_07-23-44_LIBRARY_EVP-AKE31ASW_EVP-AKE3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; 2025-10-22_07-23-44_LIBRARY_SW_EVP-AKE31A_PAN
SW_ENT: 2025-10-22_07-23-44_LIBRARY_EVP-AKE31ASW_EVP-AKE3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; 2025-10-22_07-23-44_LIBRARY_SW_EVP-AKE31A_PAN
SW_UP: 2025-10-22_07-23-44_LIBRARY_EVP-AKE31ASW_EVP-AKE3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; 2025-10-22_07-23-44_LIBRARY_SW_EVP-AKE31A_PAN
TP_3.3V, TP_3V3: HECTOR_WATCH_1_TPTP20R; HECTOR_WATCH_1_TP20R
TP_BAT_GND: HECTOR_WATCH_1_TPTP20R; HECTOR_WATCH_1_TP20R
TP_GND: HECTOR_WATCH_1_TPTP20R; HECTOR_WATCH_1_TP20R
TP_ON: HECTOR_WATCH_1_TPTP20R; HECTOR_WATCH_1_TP20R
TP_OP: HECTOR_WATCH_1_TPTP20R; HECTOR_WATCH_1_TP20R
TP_RESET: HECTOR_WATCH_1_TPTP20R; HECTOR_WATCH_1_TP20R
TP_SCL: HECTOR_WATCH_1_TPTP20R; HECTOR_WATCH_1_TP20R
TP_SDA: HECTOR_WATCH_1_TPTP20R; HECTOR_WATCH_1_TP20R
TP_SWDCLK: HECTOR_WATCH_1_TPTP20R; HECTOR_WATCH_1_TP20R
TP_SWDIO: HECTOR_WATCH_1_TPTP20R; HECTOR_WATCH_1_TP20R
TP_SWO: HECTOR_WATCH_1_TPTP20R; HECTOR_WATCH_1_TP20R
TP_VBAT: HECTOR_WATCH_1_TPTP20R; HECTOR_WATCH_1_TP20R
TP_VREG: HECTOR_WATCH_1_TPTP20R; HECTOR_WATCH_1_TP20R
U1: NRF52840_QF; NORDIC_NRF_4_AQFN50P700X700X85_HS-74N
U3: MAX17048G+T10; ESP32_C6_LIBRARY_SON50P200X200X80-9N
X1: 32MHz; NORDIC_NRF_BT-XTAL_2016_N
X2: 32.768kHz; NORDIC_NRF_1_XTAL_3215_N

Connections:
3V3/1.7D: C34.1, DMG2305UX-7.2 (S), IC2.C2 (VDD), R5.2, R7.2, R8.2, R_PWR_EPD.2
3V3/2.4A: C6.1, C7.1, C8.1, C12.1, C14.1, C19.1, C25.1, C33.1, IC3.3 (VDDIO), IC3.7 (VDD), IC3.10 (CSB), IC9.E2 (VOUT_1), IC9.E3 (VOUT_2), J2.1, R17.1, R18.1, TP_3.3V.TP, TP_3V3.TP, U1.P$A22 (VDD), U1.P$AD14 (VDD), U1.P$AD23 (VDD), U1.P$B1 (VDD), U1.P$W1 (VDD), U1.P$Y2 (VDDH)
ALERT/1.6C: U3.5 (!ALERT)
ALERT/2.5C: U1.P$J24 (P0.10/NFC2)
D+/1.5D: D3.4 (I/O2_2)
D+/2.7D: U1.P$AD6 (D+)
D-/1.5D: D3.6 (I/O1_2)
D-/2.7D: U1.P$AD4 (D-)
DN: D3.1 (I/O1_1), J4.A7 (DN1), J4.B7 (DN2)
DP: D3.3 (I/O2_1), J4.A6 (DP1), J4.B6 (DP2)
EPD_3V3: C1-EP-DR.1, DMG2305UX-7.3 (D), EPD_C5.2, J1.15, J1.16, L5.1
EPD_BUSY/1.5D: J1.9
EPD_BUSY/2.2D: U1.P$AD12 (P0.17)
EPD_CS/1.4C: J1.12
EPD_CS/2.2D: U1.P$K2 (P0.05/AIN3)
EPD_DC/1.5D: J1.11
EPD_DC/2.2D: U1.P$AD10 (P0.15)
EPD_RST/1.5D: J1.10
EPD_RST/2.2D: U1.P$AC11 (P0.16)
GDR: J1.2, Q3.1 (G), R2_EP_DR.2
GND: C1.2, C1-EP-DR.2, C2.2, C3.2, C4.2, C5.2, C6.2, C7.2, C8.2, C9.2, C10.2, C11.2, C12.2, C13.2, C14.2, C15.2, C16.2, C17.1, C18.2, C19.2, C20.2, C21.2, C22.2, C23.2, C24.1, C25.2, C27.1, C29.1, C30.1, C31.1, C32.1, C33.2, C34.2, C37.1, C38.1, C39.2, C42.2, C43.2, D3.2 (GND), D4.1 (K), EPD_C1.1, EPD_C2.1, EPD_C5.1, EPD_C6.1, EPD_C7.1, EPD_C8.1, EPD_C9.1, EPD_C10.1, EPD_C11.1, EPD_C12.1, IC1.D2 (GND), IC2.B1 (IN/TRIG), IC2.B3 (GND), IC3.8 (GNDIO), IC3.9 (GND), IC9.B1 (VSEL), IC9.C1 (AGND), IC9.C2 (PGND_1), IC9.C3 (PGND_2), J1.8, J1.17, J1.MP1, J1.MP2, J2.3, J2.5, J4.A1_B12 (GND), J4.A12_B1 (GND), J4.SH1 (SHIELD), J4.SH2 (SHIELD), J4.SH3 (SHIELD), J4.SH4 (SHIELD), R1_USB.1, R2_EP_DR.1, R2_USB.2, R3.1, R9.1, R_TYPE_SEL.1, SJ1.1, SW_DN.1, SW_ENT.1, SW_UP.1, TP_BAT_GND.TP, TP_GND.TP, U1.P$74 (VSS_PAD), U1.P$75 (VSS_PAD), U1.P$76 (VSS_PAD), U1.P$77 (VSS_PAD), U1.P$78 (VSS_PAD), U1.P$79 (VSS_PAD), U1.P$80 (VSS_PAD), U1.P$81 (VSS_PAD), U1.P$82 (VSS_PAD), U1.P$83 (VSS_PAD), U1.P$84 (VSS_PAD), U1.P$85 (VSS_PAD), U1.P$86 (VSS_PAD), U1.P$87 (VSS_PAD), U1.P$88 (VSS_PAD), U1.P$89 (VSS_PAD), U1.P$90 (VSS_PAD), U1.P$B7 (VSS), U1.P$F23 (VSS_PA), U3.1 (CTG), U3.4 (GND), U3.6 (QSTRT), U3.9 (EP), X1.2, X1.4
HAPTIC_EN/1.4C: IC2.A1 (EN)
HAPTIC_EN/2.6A: U1.P$U1 (P0.12)
IMU_INT1: U1.P$N1 (P0.08)
IMU_INT2: U1.P$P2 (P1.08)
JJ: C10.1, C15.1, C16.1, L3.2, U1.P$B5 (DEC4), U1.P$E24 (DEC6)
LX1: IC9.B2 (SW1_1), IC9.B3 (SW1_2), L7.1
LX2: IC9.D2 (SW2_1), IC9.D3 (SW2_2), L7.2
MOSI/1.5B: J1.14
MOSI/2.2D: U1.P$B13 (P0.03/AIN1)
MU_INT1: IC3.5 (INT1)
MU_INT2: IC3.6 (INT2)
unnamed: IC1.D1 (TS/MR), R9.2
unnamed: IC9.D1 (SCL), R4.2
unnamed: IC9.E1 (SDA), R2.2
unnamed: IC3.1 (SDO), R3.2
unnamed: C20.1, U1.P$AC5 (DEC3V3)
unnamed: C18.1, U1.P$F2 (P0.01/XL2), X2.1
unnamed: C17.2, U1.P$D2 (P0.00/XL1), X2.2
unnamed: C5.1, U1.P$C1 (DEC1)
unnamed: C9.1, U1.P$N24 (DEC5)
unnamed: L2.1, U1.P$B3 (DCC)
unnamed: L2.2, L3.1
unnamed: C3.1, L1.1, U1.P$H23 (ANT)
unnamed: ANT1.1 (FEED), C4.1, C22.1, L1.2
unnamed: C11.1, U1.P$D23 (DEC3)
unnamed: C2.1, U1.P$A23 (XC2), X1.3
unnamed: C1.1, U1.P$B24 (XC1), X1.1
unnamed: C2-EP-DR.1, D2.1 (K), D4.2 (A)
unnamed: R1_EP_DR.1, R_TYPE_SEL.2, SJ1.2
unnamed: C2-EP-DR.2, D5.2 (A), L5.2, Q3.3 (D)
unnamed: C13.1, U1.P$A18 (DEC2)
unnamed: C32.2, IC2.A2 (REG)
unnamed: EPD_C2.2, J1.4
unnamed: EPD_C1.2, J1.5
unnamed: EPD_C6.2, J1.18
unnamed: EPD_C7.2, J1.19
unnamed: EPD_C8.2, J1.20
unnamed: J4.A5 (CC1), R1_USB.2
unnamed: EPD_C10.2, J1.22
unnamed: EPD_C12.2, J1.24
unnamed: J4.B5 (CC2), R2_USB.1
OUT+: IC2.A3 (OUT+), TP_OP.TP
OUT-: IC2.C3 (OUT-), TP_ON.TP
P0.04: U1.P$J1 (P0.04/AIN2)
P0.09: U1.P$L24 (P0.09/NFC1)
P0.13/1.5D: C30.2, R5.1, SW_UP.2
P0.13/2.6C: U1.P$AD8 (P0.13)
P0.14/1.5D: C31.2, R8.1, SW_ENT.2
P0.14/2.7C: U1.P$AC9 (P0.14)
P0.19: U1.P$AC15 (P0.19)
P0.20: U1.P$AD16 (P0.20)
P0.21: U1.P$AC17 (P0.21)
P0.22: U1.P$AD18 (P0.22)
P0.23: U1.P$AC19 (P0.23)
P0.24: U1.P$AD20 (P0.24)
P0.25: U1.P$AC21 (P0.25)
P0.26: U1.P$G1 (P0.26)
P0.27: U1.P$H2 (P0.27)
P0.28: U1.P$B11 (P0.28/AIN4)
P0.29: U1.P$A10 (P0.29/AIN5)
P0.30: U1.P$B9 (P0.30/AIN6)
P0.31: U1.P$A8 (P0.31/AIN7)
P1.01/1.6C: DMG2305UX-7.1 (G), R_PWR_EPD.1
P1.01/2.4B: U1.P$Y23 (P1.01)
P1.02/1.6C: C29.2, R7.1, SW_DN.2
P1.02/2.8C: U1.P$W24 (P1.02)
P1.03: U1.P$V23 (P1.03)
P1.04: U1.P$U24 (P1.04)
P1.05: U1.P$T23 (P1.05)
P1.06: U1.P$R24 (P1.06)
P1.07: U1.P$P23 (P1.07)
P1.09: U1.P$R1 (P1.09)
P1.10: U1.P$A20 (P1.10)
P1.11: U1.P$B19 (P1.11)
P1.12: U1.P$B17 (P1.12)
P1.13: U1.P$A16 (P1.13)
P1.14: U1.P$B15 (P1.14)
P1.15: U1.P$A14 (P1.15)
PMIC_INT: IC1.A1 (!INT), U1.P$T2 (P0.11)
PREVGH: D5.1 (K), EPD_C9.2, J1.21
PREVGL: D2.2 (A), EPD_C11.2, J1.23
RESE: J1.3, Q3.2 (S), R1_EP_DR.2
RESET: J2.6, TP_RESET.TP, U1.P$AC13 (P0.18/RESET)
SCK/1.5B: J1.13
SCK/2.2D: U1.P$A12 (P0.02/AIN0)
SCL/1.4C: IC2.C1 (SCL), U3.7 (SCL)
SCL/2.4C: IC1.B1 (SCL), IC3.12 (SCX), R4.1, R17.2, TP_SCL.TP, U1.P$M2 (P0.07)
SDA/1.4C: IC2.B2 (SDA), U3.8 (SDA)
SDA/2.4C: IC1.C1 (SDA), IC3.2 (SDX), R2.1, R18.2, TP_SDA.TP, U1.P$L1 (P0.06)
SWDCLK: J2.4, TP_SWDCLK.TP, U1.P$AA24 (SWDCLK)
SWDIO: J2.2, TP_SWDIO.TP, U1.P$AC24 (SWDIO)
SWO: TP_SWO.TP, U1.P$AD22 (P1.00)
VBAT/1.2A: C27.2, TP_VBAT.TP, U3.2 (CELL), U3.3 (VDD)
VBAT/2.5C: C37.2, IC1.C2 (BAT)
VBUS/1.5D: C42.1, C43.1, D3.5 (VBUS), J4.A4_B9 (VBUS), J4.A9_B4 (VBUS)
VBUS/2.6D: C21.1, C38.2, IC1.A2 (IN), U1.P$AD2 (VBUS)
VREG: C23.1, C24.2, C39.1, IC1.B2 (SYS), IC9.A1 (EN), IC9.A2 (VIN_1), IC9.A3 (VIN_2), TP_VREG.TP

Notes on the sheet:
LiPo Charger
DC/DC
IMU
SWD
MCU, Power, IMU, SWD
E-Paper Drive Circuit
Haptic Driver
E-Paper Display Connector
Fuel Gauge
Buttons
E-Paper &Peripherals
USB C Connector & ESD Protection
drawn by Pascu Eric

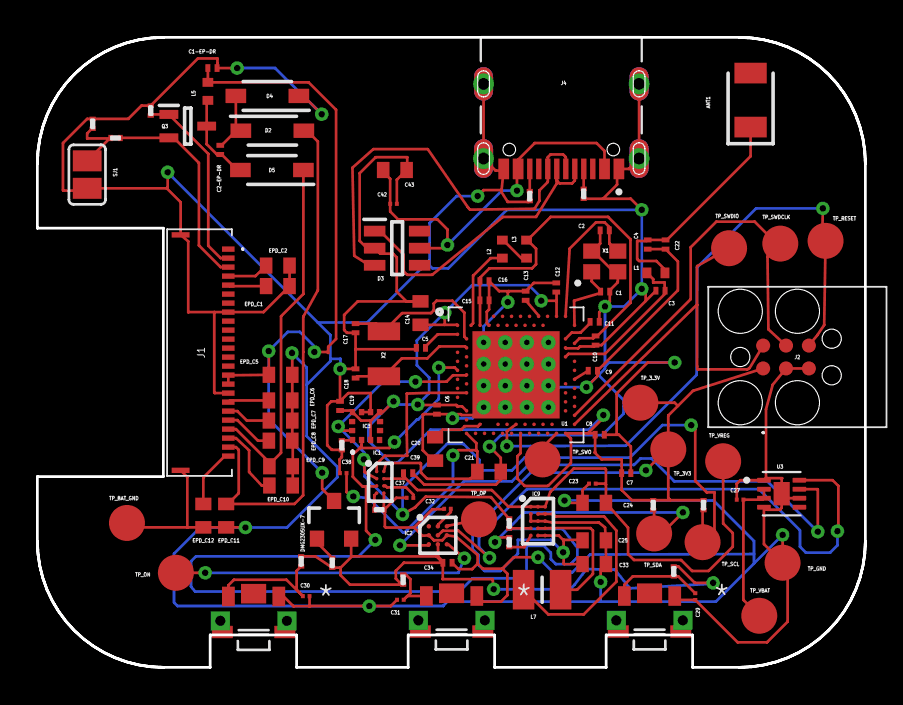
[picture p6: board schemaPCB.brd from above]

Board: 2 copper layers, 46.0 x 35.0 mm, 105 parts (0 on the bottom side), 63 nets.

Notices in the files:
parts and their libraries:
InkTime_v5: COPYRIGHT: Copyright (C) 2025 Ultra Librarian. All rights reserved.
